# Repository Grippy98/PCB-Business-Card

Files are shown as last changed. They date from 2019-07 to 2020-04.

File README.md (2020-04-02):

# PCB-Business-Card
---

Business Cards are always something that I’ve found to be sort of a nuisance. On one hand, they’re something that very few people ever have on hand, and on the other, when you do get one, you’re very likely to misplace or throw it away. That being said, they are a good way of sharing your contact details, and while I have made my own nicely designed ones on paper, I couldn’t help but think that I could make something better. My goal here was to make something that not only could I be proud to give out to possible recruiters or people I’d want to contact in the future, but I wanted to make something they’d actually WANT to keep with them or in their wallet.

Therefore I set out to design what you see before you, my very own extremely functional PCB business card. I credit it for a good number of job interviews I've gotten this past summer. It's a constant work in progress, but I'm very pleased with how it's turned out. 

###### A huge shoutout to Loann Boudin for his NFC design and for documenting it on Instructables: https://www.instructables.com/id/PCB-Business-Card-With-NFC/

### As far as the card’s functionality goes: 

1. 1S Lithium Battery Charger 
2. NFC Enabled - Have it setup to link to my Website/Resume (also demonstrates power harvesting to LED)
3. Simple logic probe that will tell you if a signal is high/low, oscillating or floating (the last two perhaps are especially useful)
4. Basic flash light (because why not) 
5. Metric/imperial Ruler
6. AWG Gauge 
7. References for trace widths in Mils 
8. Reference for PCB Font Sizes 
9. Reference for some standard component footprints

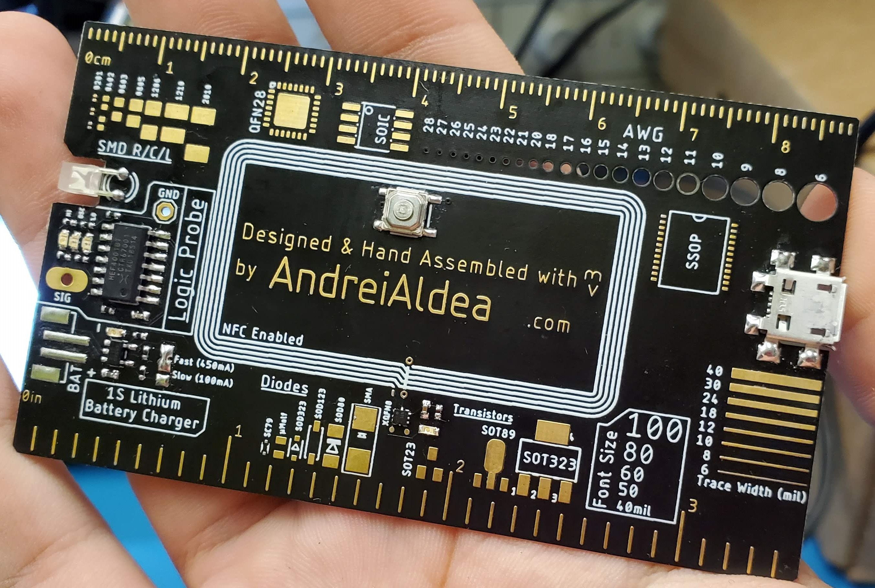
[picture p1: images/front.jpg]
PCB Front

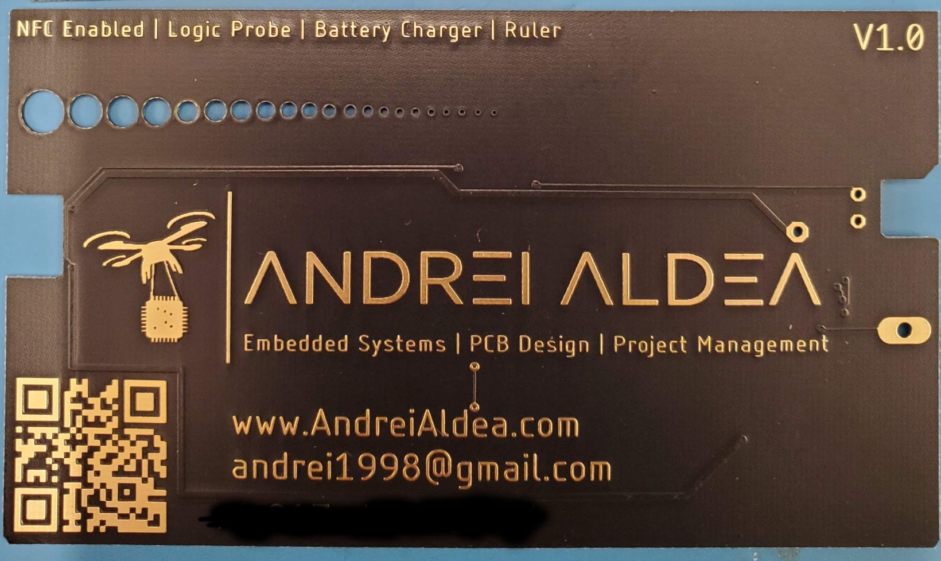
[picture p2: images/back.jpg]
PCB Back

---

### Ordering Your Own

The Boards you see were made by JLC PCB with an ENIG finnish, regular LEAD free also works. I do very much recommend you don't hand out leaded PCBs for people to handle and keep in their wallets, but that's just my two cents.

I have experimented with 0.6mm Thick Boards and above, but I recommend 0.8mm as it's thin enough while also being a bit more rigid. 

### BOM:
(TODO - fill out when I have some more time, consult schematic otherwise)
1x BRCL4054BME Power Management IC

### Notes on Soldering:

It's all rather easy to solder by hand, save for the QFN8 Package of the NFC IC, which is tough to get right, especially with Lead-free solder paste. I was able to make over 30 of these boards without defect and minor fixes by using solder masks and plenty of flux, but this is very much not beginner friendly. 

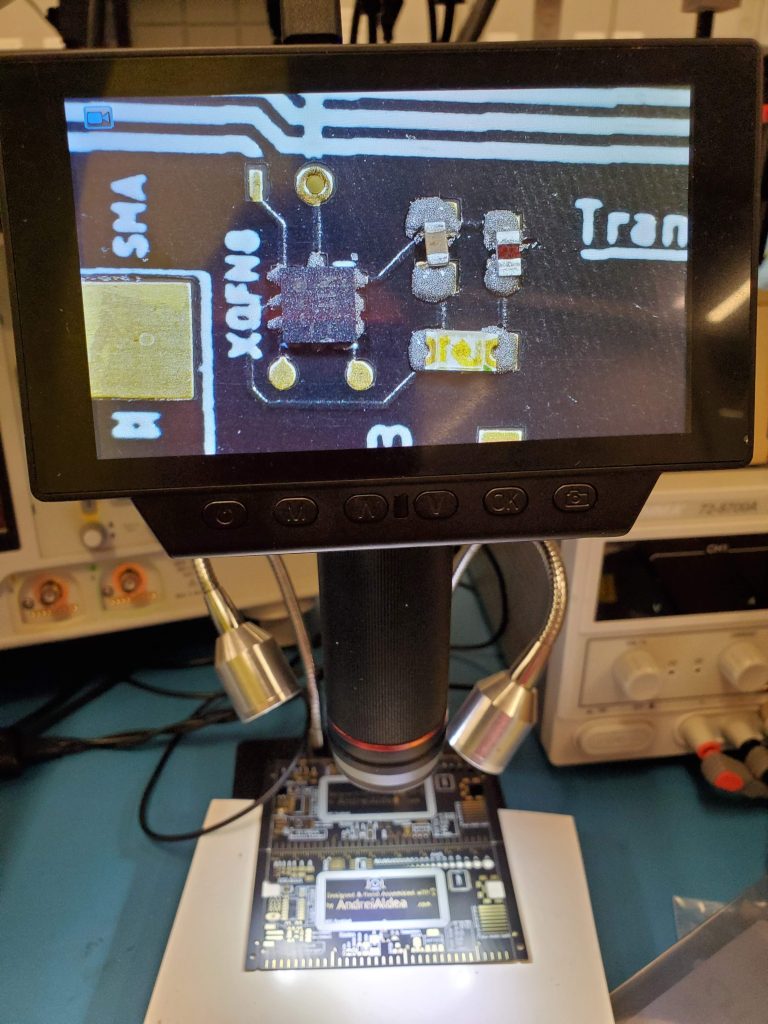
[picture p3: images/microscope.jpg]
Under the Microscope


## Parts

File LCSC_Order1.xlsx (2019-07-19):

LCSC Part Number | Manufacture Part Number | Manufacturer | Package | Description | RoHS | Order Qty. | Min\Mult Order Qty. | Unit Price | Order Price
C11958 | EVM3ESX50B25 | PANASONIC | 3*3SMD | Variable Resistors ±25% 200KOhms 3*3SMD RoHS | Yes | 30 | 10\10 | $0.0714 | $2.15
C79154 | EVPAWBD2A | PANASONIC | SMD | Tactile Switches SPST-NO 3.00mm x 2.00mm 0.60mm 20mA @ 15VDC SMD RoHS | Yes | 50 | 1\1 | $0.1105 | $5.53
C79157 | EVQ9P105M | PANASONIC | SMD | Tactile Switches SPST-NO 6.10mm x 6.00mm 5.00mm 50mA @ 12VDC SMD RoHS | Yes | 10 | 10\10 | $0.3900 | $3.9
C79172 | EVQPLHA15 | PANASONIC | SMD | Tactile Switches SPST-NO 4.90mm x 4.90mm 1.50mm 20mA @ 15VDC SMD RoHS | Yes | 40 | 20\20 | $0.1192 | $4.77
C277719 | 734120114 | MOLEX | - | RF Connectors/Coaxial Connectors RoHS | Yes | 10 | 1\1 | $0.2211 | $2.22
C293351 | 676432911 | MOLEX | Through Hole | USB Connectors Through Hole RoHS | Yes | 10 | 1\1 | $0.4693 | $4.7
C305416 | 7805 | Foshan Blue Rocket Elec | TO-220 | Linear Voltage Regulators TO-220 RoHS | Yes | 10 | 1\1 | $0.1360 | $1.36
C305473 | BAW56 | Foshan Blue Rocket Elec | SOT-23 | Switching Diode SOT-23 RoHS | Yes | 50 | 50\50 | $0.0170 | $0.85
C328563 | BRCL4054BME | Foshan Blue Rocket Elec | SOT23-5 | PMIC - Battery Management SOT23-5 RoHS | Yes | 100 | 10\10 | $0.0357 | $3.57
C328566 | LM358 | Foshan Blue Rocket Elec | SOP-8 | General Purpose Amplifiers SOP-8 RoHS | Yes | 10 | 10\10 | $0.0680 | $0.68
C328588 | MMSZ5231B | Foshan Blue Rocket Elec | SOD-123 | Zener Diodes SOD-123 RoHS | Yes | 50 | 50\50 | $0.0170 | $0.85

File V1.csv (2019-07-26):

Part | Value | Device | Package | Description | AVAILABILITY | DESCRIPTION | MF | MP | MPN | OC_FARNELL | OC_NEWARK | PACKAGE | POPULARITY | PRICE | PROD_ID | SF_SKU | SPICEPREFIX | TP_SIGNAL_NAME
BAT |  | JST_2PIN-SMT | JST-PH-2-SMT | JST 2-Pin Connectors of various flavors
C1 | 1uF | C-USC0402 | C0402 | CAPACITOR, American symbol
C2 | 220nf | C-EUC0402 | C0402 | CAPACITOR, European symbol
C3 | 100nF | C-EUC0402 | C0402 | CAPACITOR, European symbol
D3 | 100T | DIODESMA | SMADIODE | Diode
D4 | 100T | DIODESOD-123 | SOD-123 | Diode
D5 | 100T | DIODE-SOD80C | SOD80C | DIODE |  |  |  |  |  |  |  |  | 9
D6 | 100T | DIODE-SOD323-R | SOD323-R | DIODE |  |  |  |  |  |  |  |  | 4
D7 | 100T | DIODE-MICROMELF-R | MICROMELF-R | DIODE |  |  |  |  |  |  |  |  | 0
D8 | 100T | DIODE-SC79_INFINEON | SC79_INFINEON | DIODE |  |  |  |  |  |  |  |  | 0
GND |  | PINHD-1X1 | 1X01 | Pin header 1x1 for 0.1 spacing"
IC1 | 74AC02D | 74AC02D | SO14 | Quad 2-input NOR gate |  |  |  |  |  |  |  |  | 0
IC2 | PIC24FJ16GA002_QFN | PIC24FJ16GA002_QFN | QFN28-ML_6X6MM | PIC24FJ16GA002_QFN edit this description |  |  |  |  | PIC24FJ16GA002-I/ML | unknown | 40M1425
IC3 | T8C5121 | T8C5121 | SSOP24 | 8-bit Microcontroller with Multiprotocol Smart Card Interface |  |  |  |  |  | unknown | unknown
IC4 | LS7184-SOIC | LS7184-SOIC | SOIC08 | Encoder to Counter Interface |  |  |  |  |  | unknown | unknown
JMP1 | 0R-JUMPA | 0R-JUMPA | A0R-JMP | SMD 0R 0805 Jumper
LED1 | WHITE | LED3MM | LED3MM | LED |  |  |  |  |  |  |  |  | 97
LED2 | BLU | LEDCHIP-LED0603 | CHIP-LED0603 | LED
LED3 | HI | LEDSML0603 | SML0603 | LED |  |  |  |  |  |  |  |  | 17
LED4 | LO | LEDSML0603 | SML0603 | LED |  |  |  |  |  |  |  |  | 17
LED5 | OSC | LEDSML0603 | SML0603 | LED |  |  |  |  |  |  |  |  | 17
LED6 | BLU | LEDSML0603 | SML0603 | LED |  |  |  |  |  |  |  |  | 17
NT3H1101 | NT3H1101 | NT3H1101 | XQFN8
P1 | ZX62M-B-5P(01) | ZX62M-B-5P(01) | HRS_ZX62M-B-5P(01) | Conn Micro USB 2.0 Type B RCP 5 POS 0.65mm Solder RA SMD 5 Terminal 1 Port T/R | Unavailable | Conn Rcpt Micro Usb b Mid Mnt | Hirose | ZX62M-B-5P |  |  |  | None |  | None
PROBE |  | PINHD-1X1-BIGPOGO | 1X1-BIGPOGO | Pin header 1x1 for 0.1 spacing"
Q1 | 100T | NPN-TRANSISTIOR-2COLSOT89 | SOT89 | NPN TRANSISTOR
R1 | 2.2K | R-US_R0402 | R0402 | RESISTOR, American symbol |  |  |  |  |  |  |  |  | 34 |  |  |  | R
R2 | 1k | R-US_R0402 | R0402 | RESISTOR, American symbol |  |  |  |  |  |  |  |  | 34 |  |  |  | R
R3 | 47 | R-US_R0402 | R0402 | RESISTOR, American symbol |  |  |  |  |  |  |  |  | 34 |  |  |  | R
R4 | 10K | R-US_R0402 | R0402 | RESISTOR, American symbol |  |  |  |  |  |  |  |  | 34 |  |  |  | R
R5 | 330 | R-US_R0402 | R0402 | RESISTOR, American symbol |  |  |  |  |  |  |  |  | 34 |  |  |  | R
R6 | 2.2M | R-US_R0402 | R0402 | RESISTOR, American symbol |  |  |  |  |  |  |  |  | 34 |  |  |  | R
R7 | 1k | R-US_R0402 | R0402 | RESISTOR, American symbol |  |  |  |  |  |  |  |  | 34 |  |  |  | R
R8 | 1k | R-US_R0402 | R0402 | RESISTOR, American symbol |  |  |  |  |  |  |  |  | 34 |  |  |  | R
R9 | 4.7M | R-US_R0402 | R0402 | RESISTOR, American symbol |  |  |  |  |  |  |  |  | 34 |  |  |  | R
R10 | 1k | R-US_R0402 | R0402 | RESISTOR, American symbol |  |  |  |  |  |  |  |  | 34 |  |  |  | R
R11 | 100T | R-US_R0201 | R0201 | RESISTOR, American symbol |  |  |  |  |  |  |  |  | 0 |  |  |  | R
R12 | 100T | R-US_R0201 | R0201 | RESISTOR, American symbol |  |  |  |  |  |  |  |  | 0 |  |  |  | R
R13 | 100T | R-US_R0201 | R0201 | RESISTOR, American symbol |  |  |  |  |  |  |  |  | 0 |  |  |  | R
R14 | 100T | R-US_R0402 | R0402 | RESISTOR, American symbol |  |  |  |  |  |  |  |  | 34 |  |  |  | R
R15 | 100T | R-US_R0402 | R0402 | RESISTOR, American symbol |  |  |  |  |  |  |  |  | 34 |  |  |  | R
R16 | 100T | R-US_R0603 | R0603 | RESISTOR, American symbol |  |  |  |  |  |  |  |  | 77 |  |  |  | R
R17 | 100T | R-US_R0805 | R0805 | RESISTOR, American symbol |  |  |  |  |  |  |  |  | 85 |  |  |  | R
R18 | 100T | R-US_R1206 | R1206 | RESISTOR, American symbol |  |  |  |  |  |  |  |  | 19 |  |  |  | R
R19 | 100T | R-US_R1210 | R1210 | RESISTOR, American symbol |  |  |  |  |  |  |  |  | 0 |  |  |  | R
R20 | 100T | R-US_R2010 | R2010 | RESISTOR, American symbol |  |  |  |  |  |  |  |  | 0 |  |  |  | R
S1 | MOMENTARY-SWITCH-SPST-SMD-5.2-REDUNDANT | MOMENTARY-SWITCH-SPST-SMD-5.2-REDUNDANT | TACTILE_SWITCH_SMD_5.2MM | Momentary Switch (Pushbutton) - SPST |  |  |  |  |  |  |  |  |  |  | SWCH-08247 | COM-08720
T1 | 100T | -NPN-SOT23-EBC | SOT23-EBC | NPN Transistror |  |  |  |  |  |  |  |  | 0
T2 | 100T | NPNSOT223 | SOT223 | NPN TRANSISTOR |  |  |  |  | DJT4031N-13 | 1710672 | 25R4490
TP1 | TPTP06R | TPTP06R | TP06R | Test pad
TP2 | TPTP06R | TPTP06R | TP06R | Test pad
U$1 | NFC_ANT_48X25 | NFC_ANT_48X25 | NFC_ANT_48X25
U$3 | HX4054A | HX4054A | SOT23-5L

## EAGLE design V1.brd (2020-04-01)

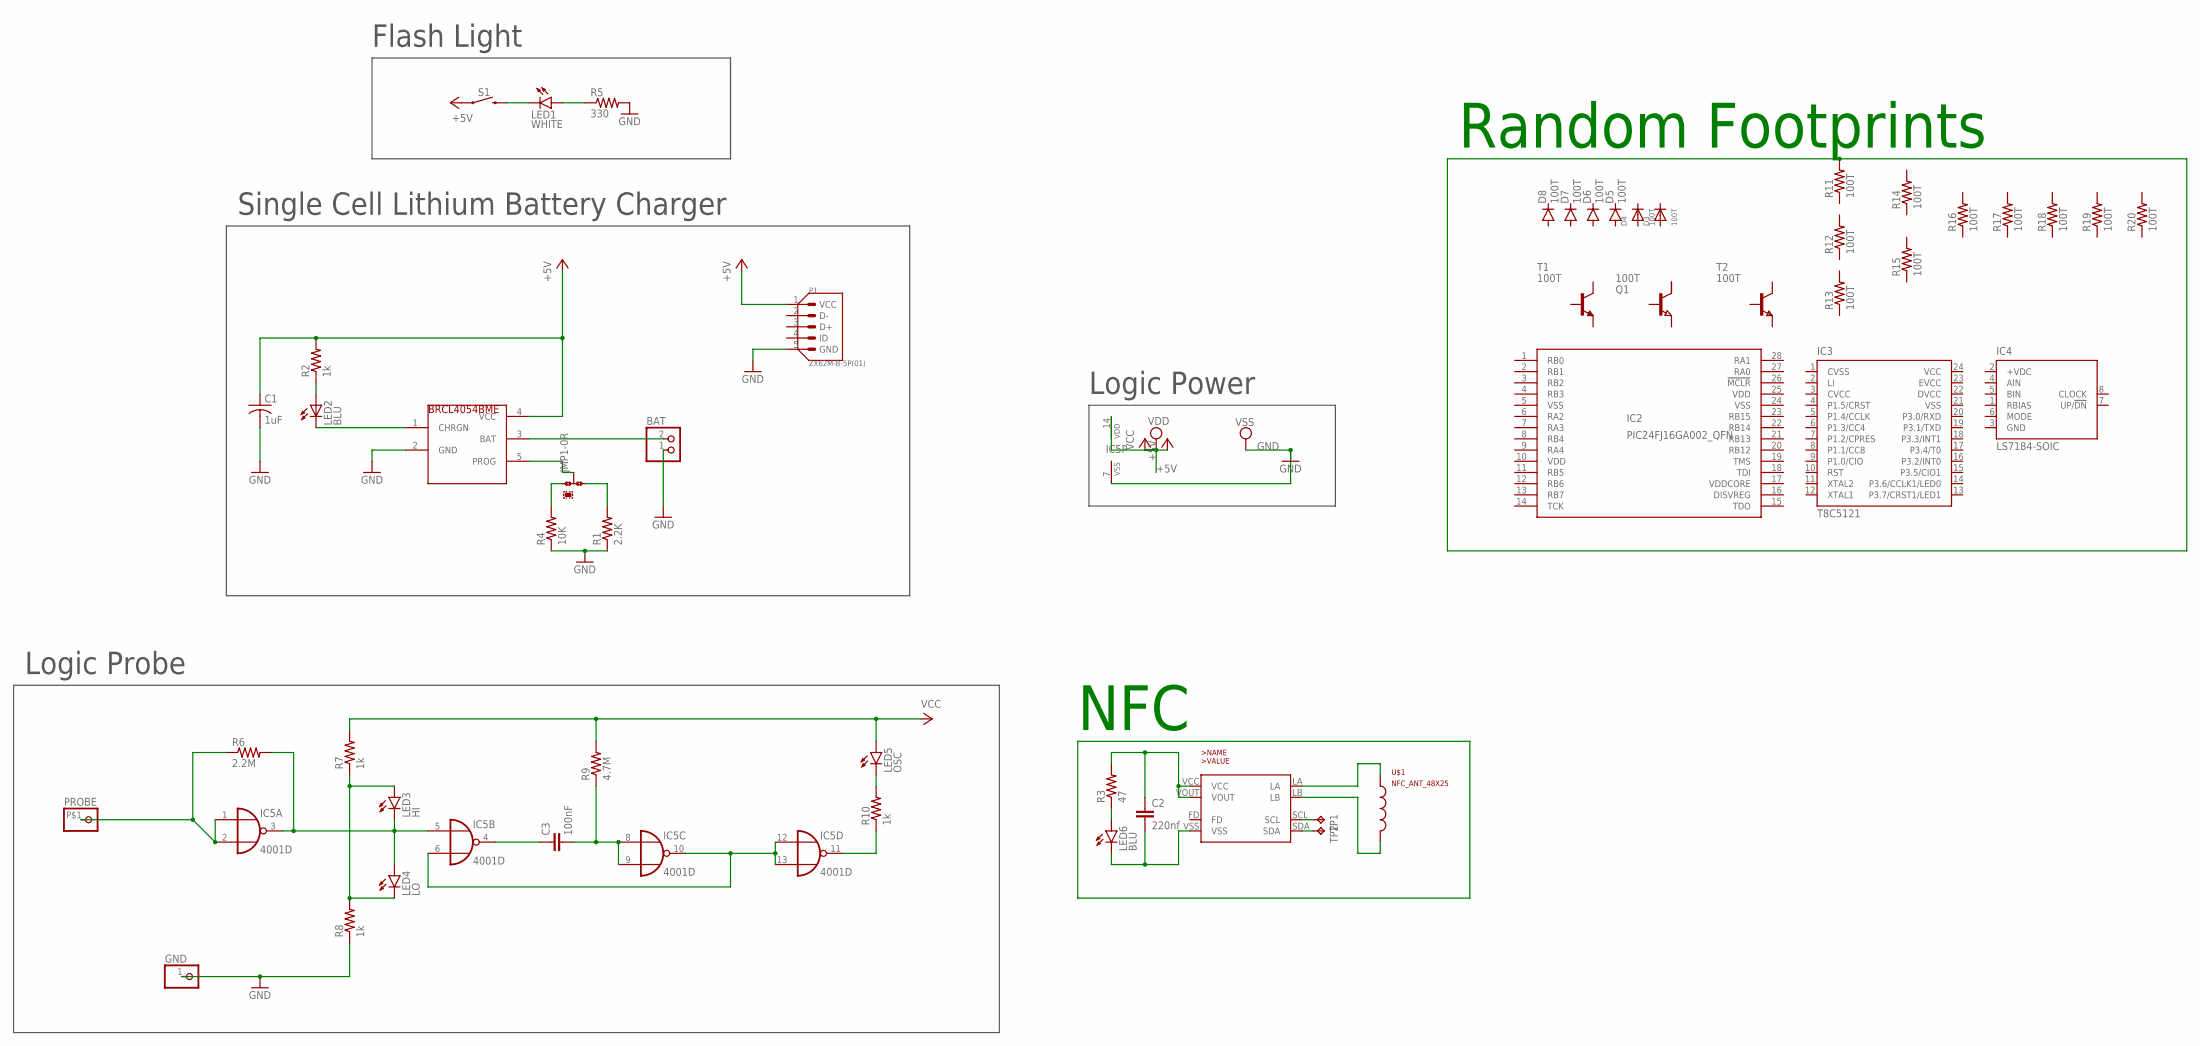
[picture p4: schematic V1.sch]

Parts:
BAT: JST_2PIN-SMT; JST-PH-2-SMT
C1: 1uF; C0402
C2: 220nf; C0402
C3: 100nF; C0402
D3: 100T; SMADIODE
D4: 100T; SOD-123
D5: 100T; SOD80C
D6: 100T; SOD323-R
D7: 100T; MICROMELF-R
D8: 100T; SC79_INFINEON
GND: PINHD-1X1; 1X01
IC2: PIC24FJ16GA002_QFN; QFN28-ML_6X6MM
IC3: T8C5121; SSOP24
IC4: LS7184-SOIC; SOIC08
IC5: 4001D; SO14
JMP1: 0R-JUMPA; A0R-JMP
LED1: WHITE; LED3MM
LED2: BLU; CHIP-LED0603
LED3: HI; SML0603
LED4: LO; SML0603
LED5: OSC; SML0603
LED6: BLU; SML0603
NT3H1101: NT3H1101; XQFN8
P1: ZX62M-B-5P(01); HRS_ZX62M-B-5P(01)
PROBE: PINHD-1X1-BIGPOGO; 1X1-BIGPOGO
Q1: 100T; SOT89
R1: 2.2K; R0402
R2, R7, R8, R10: 1k; R0402
R3: 47; R0402
R4: 10K; R0402
R5: 330; R0402
R6: 2.2M; R0402
R9: 4.7M; R0402
R11, R12, R13: 100T; R0201
R14, R15: 100T; R0402
R16: 100T; R0603
R17: 100T; R0805
R18: 100T; R1206
R19: 100T; R1210
R20: 100T; R2010
S1: MOMENTARY-SWITCH-SPST-SMD-5.2-REDUNDANT; TACTILE_SWITCH_SMD_5.2MM
T1: 100T; SOT23-EBC
T2: 100T; SOT223
TP1, TP2: TPTP06R; TP06R
U$1: NFC_ANT_48X25
U$3: HX4054A; SOT23-5L

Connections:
+5V: C1.1, IC2.10 (VDD), IC2.25 (VDD), IC3.24 (VCC), IC5.14 (VDD), P1.1 (VCC), R2.2, S1.1, S1.2 (1), U$3.4 (VCC)
CVCC: IC3.3 (CVCC)
CVSS: IC3.1 (CVSS)
DVCC: IC3.22 (DVCC)
GND: BAT.1 (2), C1.2, GND.1, IC2.5 (VSS), IC2.24 (VSS), IC3.21 (VSS), IC4.3 (GND), IC5.7 (VSS), P1.5 (GND), R1.1, R4.1, R5.2, R8.1, U$3.2 (GND)
LI: IC3.2 (LI)
unnamed: JMP1.3, R1.2
unnamed: LED2.A, R2.1
unnamed: LED2.C, U$3.1 (CHRGN)
unnamed: BAT.2 (1), U$3.3 (BAT)
unnamed: JMP1.2, U$3.5 (PROG)
unnamed: LED1.A, R5.1
unnamed: IC5.6 (I1), IC5.10 (O), IC5.12 (I0), IC5.13 (I1)
unnamed: IC5.1 (I0), IC5.2 (I1), PROBE.P$1, R6.1
unnamed: LED3.A, LED4.C, R7.1, R8.2
unnamed: C3.2, IC5.8 (I0), R9.1
unnamed: NT3H1101.LA, U$1.A
unnamed: NT3H1101.LB, U$1.B, U$1.P$3 (B)
unnamed: C2.1, NT3H1101.VCC, NT3H1101.VOUT, R3.2
unnamed: LED6.A, R3.1
unnamed: C2.2, LED6.C, NT3H1101.VSS
unnamed: IC5.3 (O), IC5.5 (I0), LED3.C, LED4.A, R6.2
unnamed: NT3H1101.SDA, TP2.TP
unnamed: NT3H1101.SCL, TP1.TP
unnamed: C3.1, IC5.4 (O)
unnamed: IC5.11 (O), R10.1
unnamed: LED5.C, R10.2
unnamed: JMP1.1, R4.2
unnamed: LED1.K (C), S1.3 (2), S1.4 (2)
VCC: LED5.A, R7.2, R9.2
VDDCORE: IC2.17 (VDDCORE)

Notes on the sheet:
Logic Probe
Single Cell Lithium Battery Charger
Flash Light
Logic Power
Random Footprints
NFC

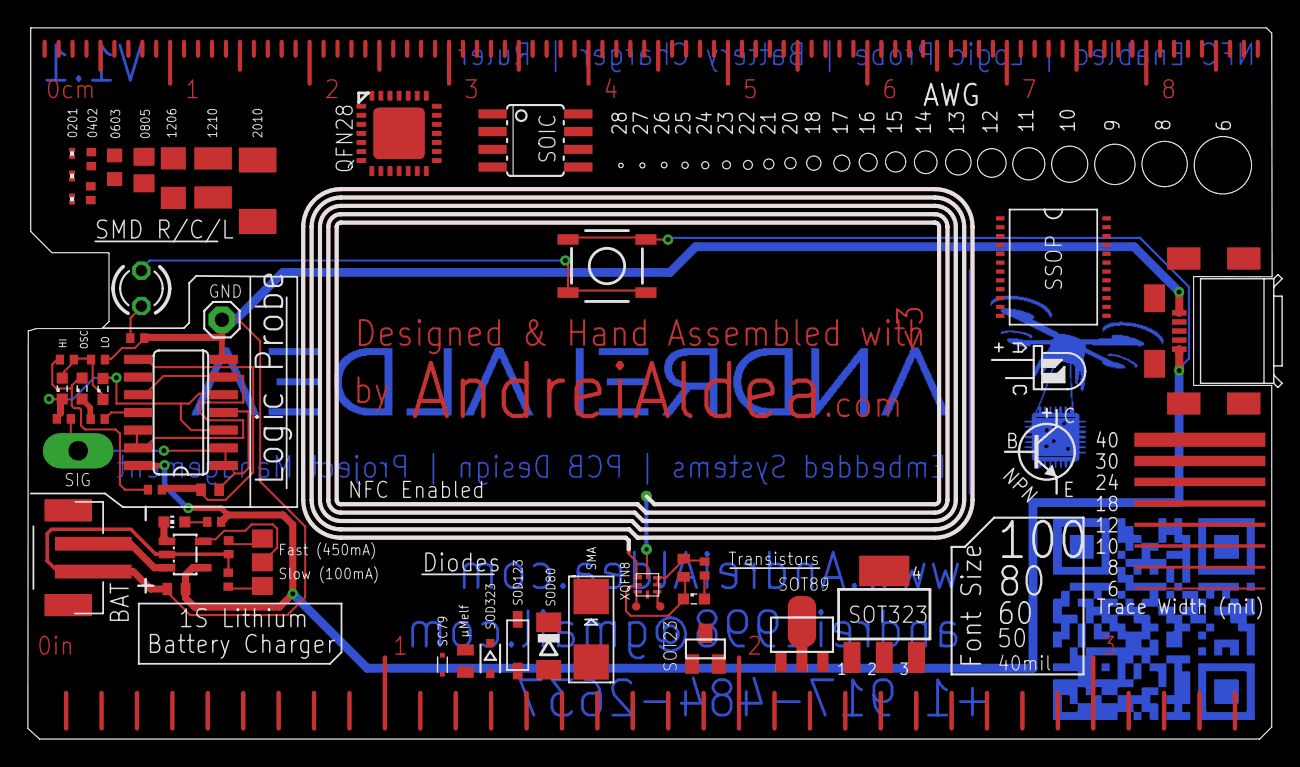
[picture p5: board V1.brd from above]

Board: 2 copper layers, 89.2 x 51.0 mm, 57 parts (1 on the bottom side), 26 nets.

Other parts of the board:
E$54: NPN-SYMB
E$74: LED-GUIDE
U$2: IMPERIAL
U$4: METRIC

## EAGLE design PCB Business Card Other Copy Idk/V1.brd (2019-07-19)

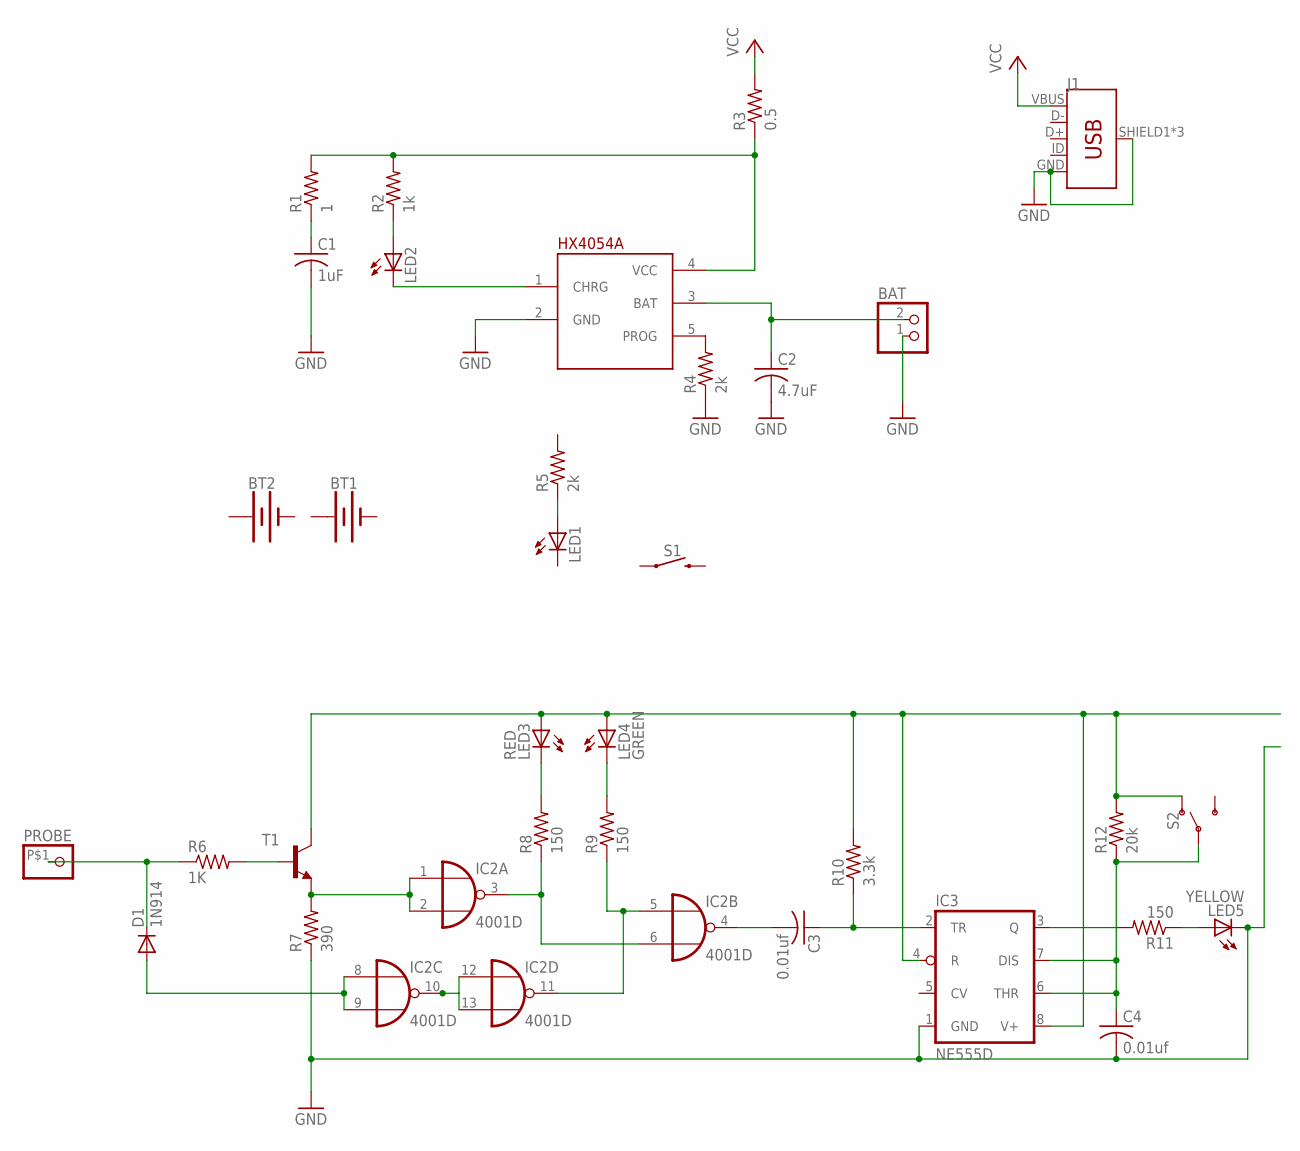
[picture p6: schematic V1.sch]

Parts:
BAT: JST_2PIN-SMT; JST-PH-2-SMT
BT1, BT2: BATTERY-12MM_SMD; BATTCON_12MM
C1: 1uF; C0402
C2: 4.7uF; C0402
C3, C4: 0.01uf; C0402
D1: 1N914; SOD323-W
IC2: 4001D; SO14
IC3: NE555D; SO08
J1: USB_MICRO-BREDUCED_PASTE; USB-B-MICRO-SMD_RED_PASTE
LED1: LED3MM
LED2: LEDCHIP-LED0603; CHIP-LED0603
LED3: RED; CHIP-LED0603
LED4: GREEN; CHIP-LED0603
LED5: YELLOW; CHIP-LED0603
PROBE: PINHD-1X1-BIGPOGO; 1X1-BIGPOGO
R1: 1; R0201
R2: 1k; R0201
R3: 0.5; R0402
R4: 2k; R0201
R5: 2k; R0603
R6: 1K; R0402
R7: 390; R0402
R8, R9, R11: 150; R0402
R10: 3.3k; R0402
R12: 20k; R0402
S1: MOMENTARY-SWITCH-SPST-SMD-5.2-REDUNDANT; TACTILE_SWITCH_SMD_5.2MM
S2: SWITCH-SPDT-PTH-11.6X4.0MM; SWITCH_SPDT_PTH_11.6X4.0MM
T1: MMBT2222ALT1-NPN-SOT23-BEC; SOT23-BEC
U$3: HX4054A; SOT23-5L

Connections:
+: BT1.PWR@1 (+), BT2.PWR@1 (+)
-: BT1.GND (-), BT2.GND (-)
GND: BAT.1 (2), C1.2, C2.2, C4.2, IC3.1 (GND), J1.GND, J1.SHIELD1 (SHIELD), J1.SHIELD2 (SHIELD), J1.SHIELD3 (SHIELD), LED5.C, R4.1, R7.1, U$3.2 (GND)
unnamed: C1.1, R1.1
unnamed: R1.2, R2.2, R3.1, U$3.4 (VCC)
unnamed: LED2.A, R2.1
unnamed: LED2.C, U$3.1 (CHRG)
unnamed: BAT.2 (1), C2.1, U$3.3 (BAT)
unnamed: R4.2, U$3.5 (PROG)
unnamed: LED1.A, R5.1
unnamed: R6.2, T1.B
unnamed: D1.C, PROBE.P$1, R6.1
unnamed: D1.A, IC2.8 (I0), IC2.9 (I1)
unnamed: IC2.10 (O), IC2.12 (I0), IC2.13 (I1)
unnamed: IC2.1 (I0), IC2.2 (I1), R7.2, T1.E
unnamed: LED3.C, R8.2
unnamed: LED4.C, R9.2
unnamed: IC2.3 (O), IC2.6 (I1), R8.1
unnamed: IC2.5 (I0), IC2.11 (O), R9.1
unnamed: LED5.A, R11.1
unnamed: IC3.3 (Q), R11.2
unnamed: C3.2, IC2.4 (O)
unnamed: C3.1, IC3.2 (TR), R10.1
unnamed: C4.1, IC3.6 (THR), IC3.7 (DIS), R12.1, S2.2
unnamed: IC3.4 (R), IC3.8 (V+), LED3.A, LED4.A, R10.2, R12.2, S2.1 (O), T1.C
VCC: J1.VBUS, R3.2
VDD: IC2.14 (VDD)
VSS: IC2.7 (VSS)

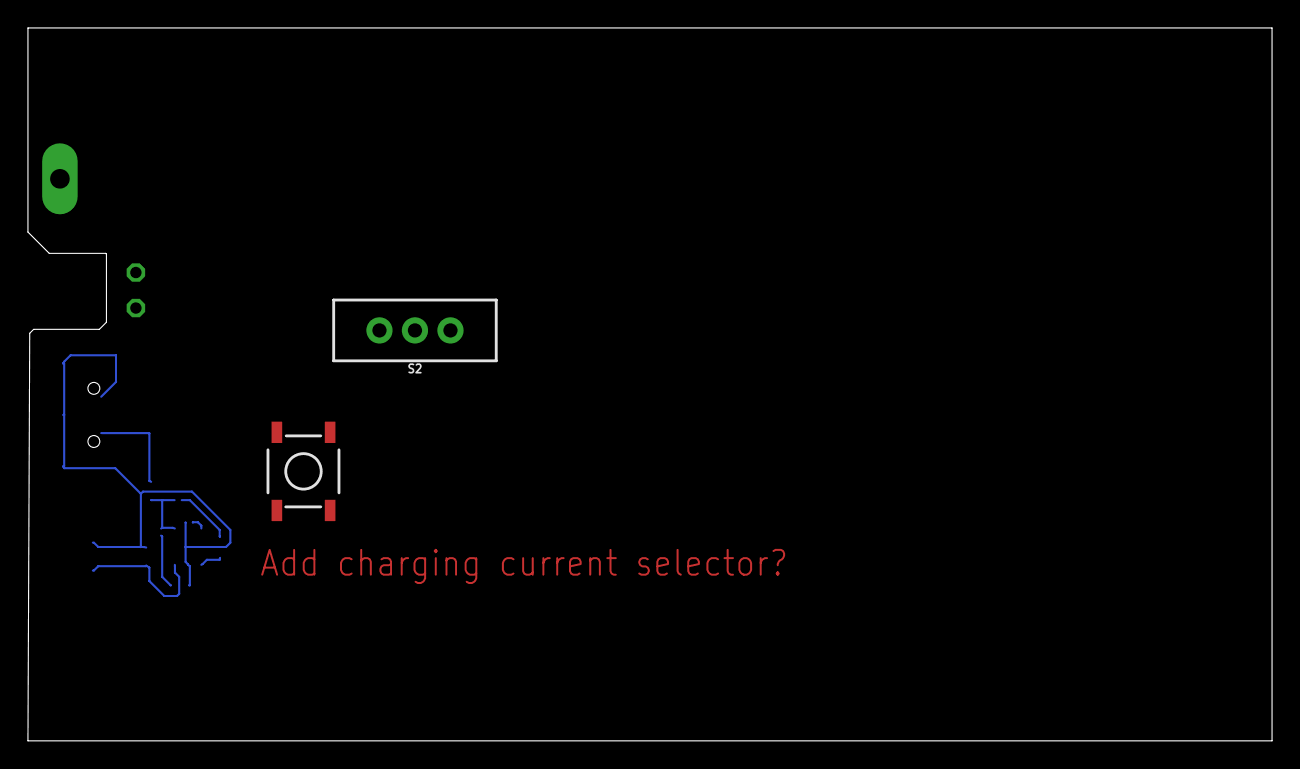
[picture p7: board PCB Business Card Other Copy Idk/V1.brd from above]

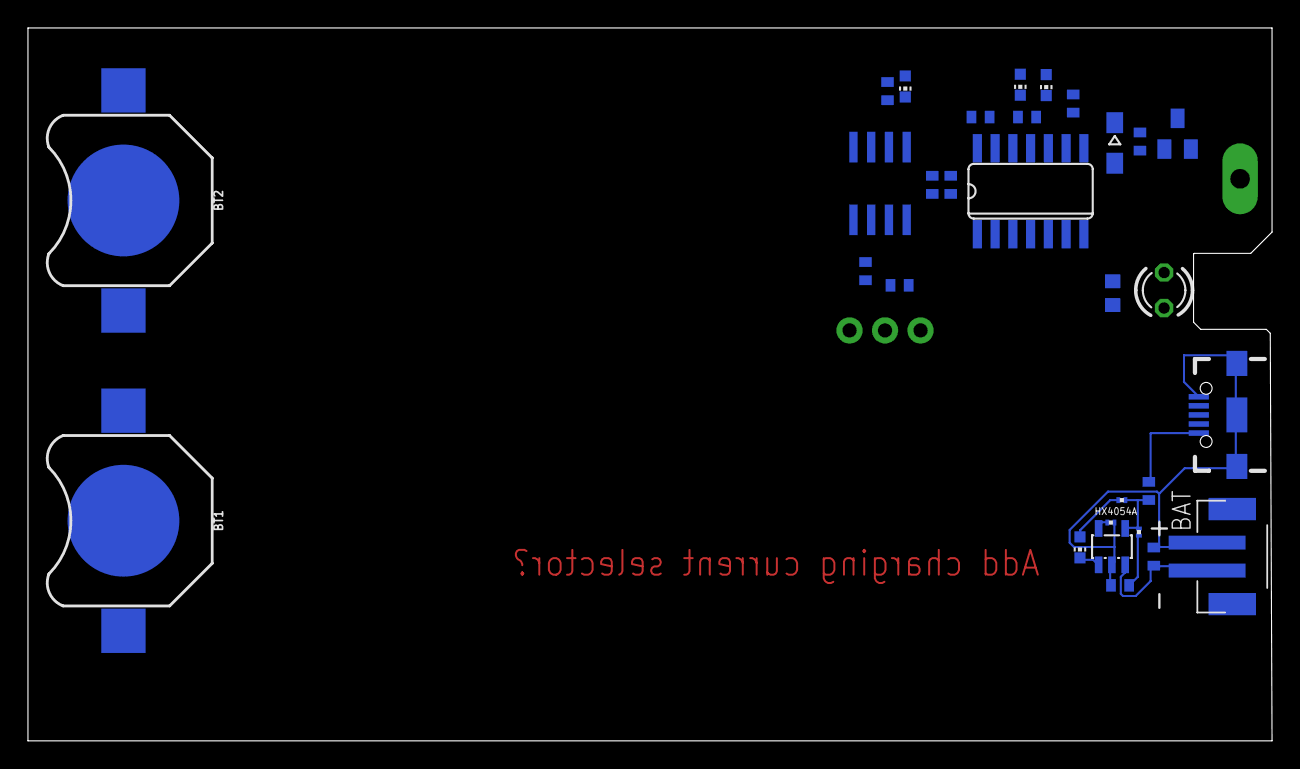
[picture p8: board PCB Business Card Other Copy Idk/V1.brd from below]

Board: 2 copper layers, 89.0 x 51.0 mm, 35 parts (30 on the bottom side), 26 nets.

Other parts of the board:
U$1: METRIC
U$2: IMPERIAL

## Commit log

2019-07-24 O no I'm getting ideas
    [V1.brd, V1.sch]
2019-07-25 Really Proud of How its TUrning out... Almost done
    [V1.brd, V1.sch]
2019-07-26 V1 Completed
    [V1.brd, V1.csv, V1.sch]
2019-07-29 Version that went into production
    [V1.brd]
2019-08-02 4001 and 74 Series logic Pinout is Different... DOH
    [V1.brd, V1.sch]
2019-08-26 I made changes aparently
    [V1.brd, V1.sch]
2019-08-29 V1.1 Ordered From JLC
    [V1.brd, V1.sch]
2020-04-01 Cleanning Up
    [LCSC_Order1.xlsx, V1.brd, V1.csv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]

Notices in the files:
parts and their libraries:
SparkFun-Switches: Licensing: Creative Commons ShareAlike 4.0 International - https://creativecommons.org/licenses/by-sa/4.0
